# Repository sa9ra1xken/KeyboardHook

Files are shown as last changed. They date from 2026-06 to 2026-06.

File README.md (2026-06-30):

# Objective

This project aims to remodel a 1980s electronic typewriter into an online terminal in order to recreate the computing environment of the 1970s.
The project uses a Canon electronic typewriter Model S-14 which employs a daisy-wheel impact printing mechanism, manufactured in 1986.
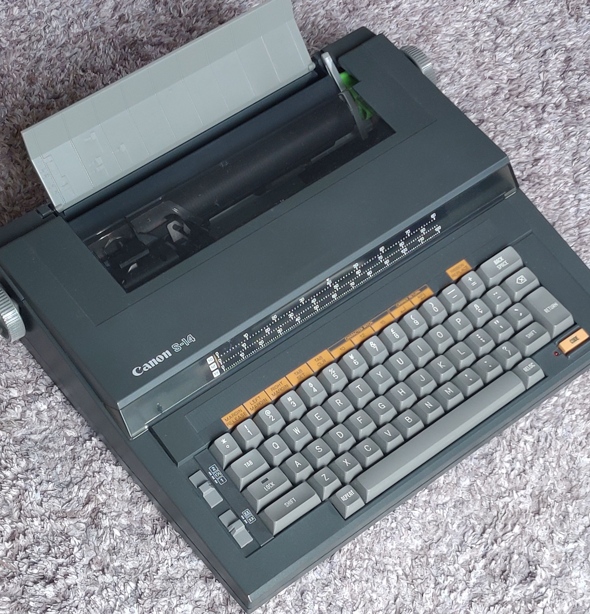
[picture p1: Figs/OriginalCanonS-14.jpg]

 
# Technical approrch

It looks the keyboard is the only available device to order printing operation, my aproach is to interfare the keyboard matrix with additionaly equipped switing device. 
An Arduino-based controller manipulates CMOS analog switches placed between scan lines and sense lines of the keyboard matrix to print characters sent from a host computer.
The controller also monitors user input by tracking behavior on the scan and sense lines, and transmits the input characters to the host.

# keyboard matrix and scan code

The keyboard matrix consists of eight scan lines and eight sense lines. Each key are maped on a pair of one scan line and one sense line. Each scan line is sequencially activated one by one. The controler knows which key is pressed by checking the sense line state at the timing each scan line is activated. 
The following table shows the key mapping in the matrix on the unit. 

|scan\sense|pin12(COL0)|pin11(COL1)|pin10(COL2)|pin9(COL3)|pin8(COL4)|pin7(COL5)|pin6(COL6)|pin5(COL7)|
|:---:|:---:|:---:|:---:|:---:|:---:|:---:|:---:|:---:|
|pin21(ROW0)|REP |A |I |Q |Y |6 |/ |TAB |
|pin20(ROW1)|SHIFT |B |J |R |Z |7 |^ |DEL |
|pin19(ROW2)|LOCK |C |K |S |0 |8 |- |REPEAT |
|pin18(ROW3)| |D |L |T |1 |9 |= |BS |
|pin17(ROW4)| |E |M |U |2 |, |β |CODE |
|pin16(ROW5)| |F |N |V |3 |. | | |
|pin15(ROW6)| |G |O |W |4 |, |° | |
|pin14(ROW7)| |H |P |X |5 |. |space | |

In the Arduino internal process, a key press is represented by the intermediate byte of information called the scan code.
Below is the bit structure of the scan code.

|Bit7|Bit6|Bit5|Bit4|Bit3|bit2|Bit1|Bit0|
|----|----|----|----|----|----|----|----|
|0 |0 |C[2]|C[1]|C[0]|R[2]|R[1]|R[0]|

C[i] means bit i in the binary encoded colmn number, R[j] means bit j in the binary encoded row number.

# Handshaking

Since the printing speed of the typewriter is usually much slower than the host computer, we have to implement some mechanism to synchronaize the data rate between them. The mechanism makes the host computer wait sending character untile the typewriter has processed the last character.
In order to know the state of mechanical behavior in the typewriter, a couple of logic signal on the embeded controller IC7 (HD6301Y) on the main typewriter control board are monitored by the adapter. I have discoverd these signals by some oscilloscoping.

|Signal|Function|Connection to Arduino|
|---|---|---|
|IC7.Pin24|Goes low while typing a character|D3|
|IC7.Pin16|Goes high while feeding paper|D7|

Regarding the handshaking between Arduino and the host, I initially intended to use the CTS signal on the serial port, but I couldn't get the host side to handle CTS-based handshaking. I decided to use ACK-based handshaking,   where Arduino sends back an ACK character (0x06) upon processing a character from the host.

# Printing usupported characters

Because the typewriter was originally not intended to be used with computers, several characters defined in the ASCII code table were missing. To cope with this limitation, I have implemented a method to express unsupported characters by overtyping multiple caracters. 
Below shows the unsupported characters and the replaced overtyping combination I used. 

|Original character|Replacement|
|---|---|
|'<' |'(' and '-'|
|'>' |')' and '-'|
|'{' |'(' and '='|
|'}' |')' and '='|
|'[' |'(' and '_'|
|']' |')' and '_'|
 
# Inputting unsupported characters 

There is a special button named CODE on the keyboard.
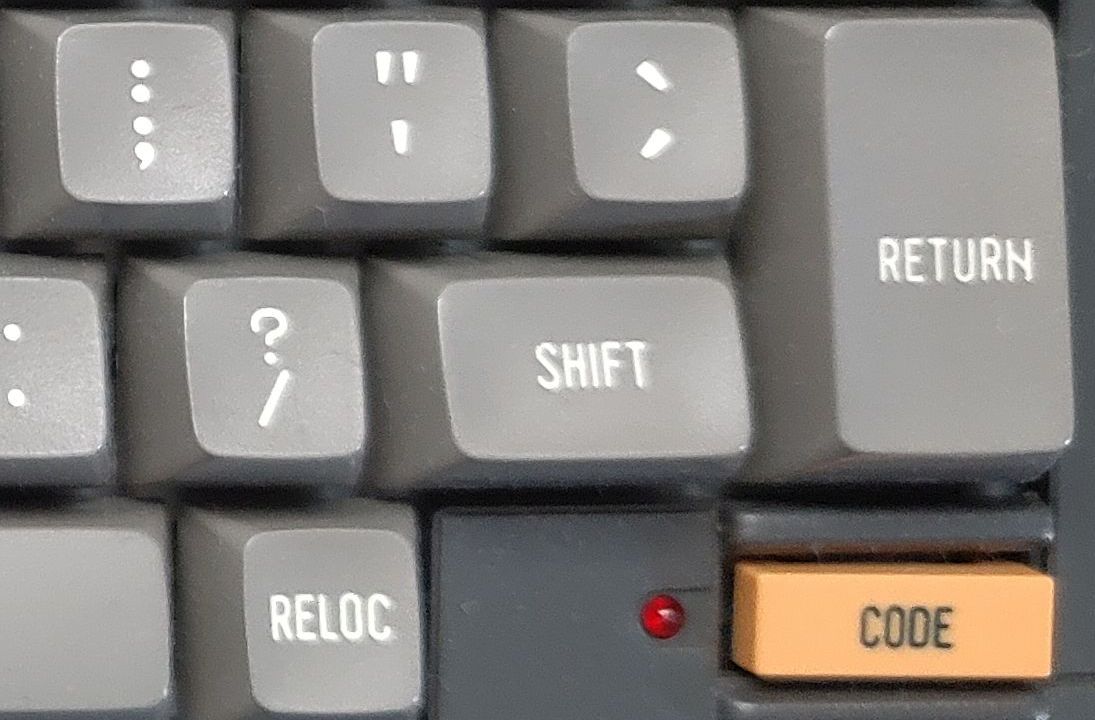
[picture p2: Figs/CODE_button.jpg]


The original function of the button is to bring the typewriter into special mode in which you can change some operating parameters such as Left and Right Margins, TAB position, character pitch, etc. I named the mode "CODE mode".         
Since pressing any of the alphabet keys when the typewriter is in CODE mode doesn't make printing action, I used CODE mode for inputting the unsupported characters and some ASCII control codes. Below shows the key functions in CODE mode I implemented.

|Key |Function in CODE mode |
|---|---|
|B |Send CTRL-B (STX) to host |
|C |Send CTRL-C (ETX) to host |
|D |Send CTRL-D (EOT) to host |
|E |Send CTRL-E (ENQ) to host |
|F |Send CTRL-F (ESC) to host |
|J |behaves as '<' key |
|K |behaves as '>' key |
|L |behaves as '[' key |
|L with SHIFT|behaves as '{' key | 
|M |behaves as ']' key |
|M with SHIFT|behaves as '}' key |  

By the way, though pressing alphabet keys in CODE mode doesn't print, some variation in behavior results, as shown in the following table. Program code in Arduino absorbs these variations.  

|Key|Behavior in CODE mode|
|--|:---|
|A|sounds beep|
|B|Print a blank character then exit CODE mode|
|C|sounds beep and exits CODE mode|
|D-I|sounds beep|
|J-M|Do nothing and exit CODE mode|
|N-Z|sounds beep|

# Sumary of adapter interface

|pin#|in/out|signal function |main board connection  |
|----|---|---|---|
|1 | | | |
|2 | | | |
|3 |in |+feed in progress  |IC7.Pin16 |
|4 | | | |
|5 | | | |
|6 | | | |
|7 |in |-print in progress |IC7.pin24 |
|8 |pass. |KBD matrix ROW0 |FFC.pin21 |
|9 |pass. |KBD matrix ROW1 |FFC.pin20 |
|10  |pass. |KBD matrix ROW2 |FFC.pin19 |
|11  |pass. |KBD matrix ROW3 |FFC.pin18 |
|12  |pass. |KBD matrix ROW4 |FFC.pin17 |
|13  |pass. |KBD matrix ROW6 |FFC.pin16 |
|14  |pass. |KBD matrix ROW6 |FFC.pin15 |
|15  |pass. |KBD matrix ROW7 |FFC.pin14 |
|16  |pass. |KBD matrix COL0 |FFC.pin13 |
|17  |pass. |KBD matrix COL1 |FFC.pin12 |
|18  |pass. |KBD matrix COL2 |FFC.pin11 |
|19  |pass. |KBD matrix COL3 |FFC.pin10 |
|20  |pass. |KBD matrix COL4 |FFC.pin9 |
|21  |pass. |KBD matrix COL5 |FFC.pin8 |
|22  |pass. |KBD matrix COL6 |FFC.pin7 |
|23  |pass. |KBD matrix COL7 |FFC.pin6 |
|24  |power |ground |FFC.pin5 |
|25  | | |FFC.pin4 |
|26  |in |-shift lock |FFC.pin3 |
|27  |in |-CODE mode |FFC.pin2 |
|28  |power |power supply(+5V)  |FFC.pin1 |

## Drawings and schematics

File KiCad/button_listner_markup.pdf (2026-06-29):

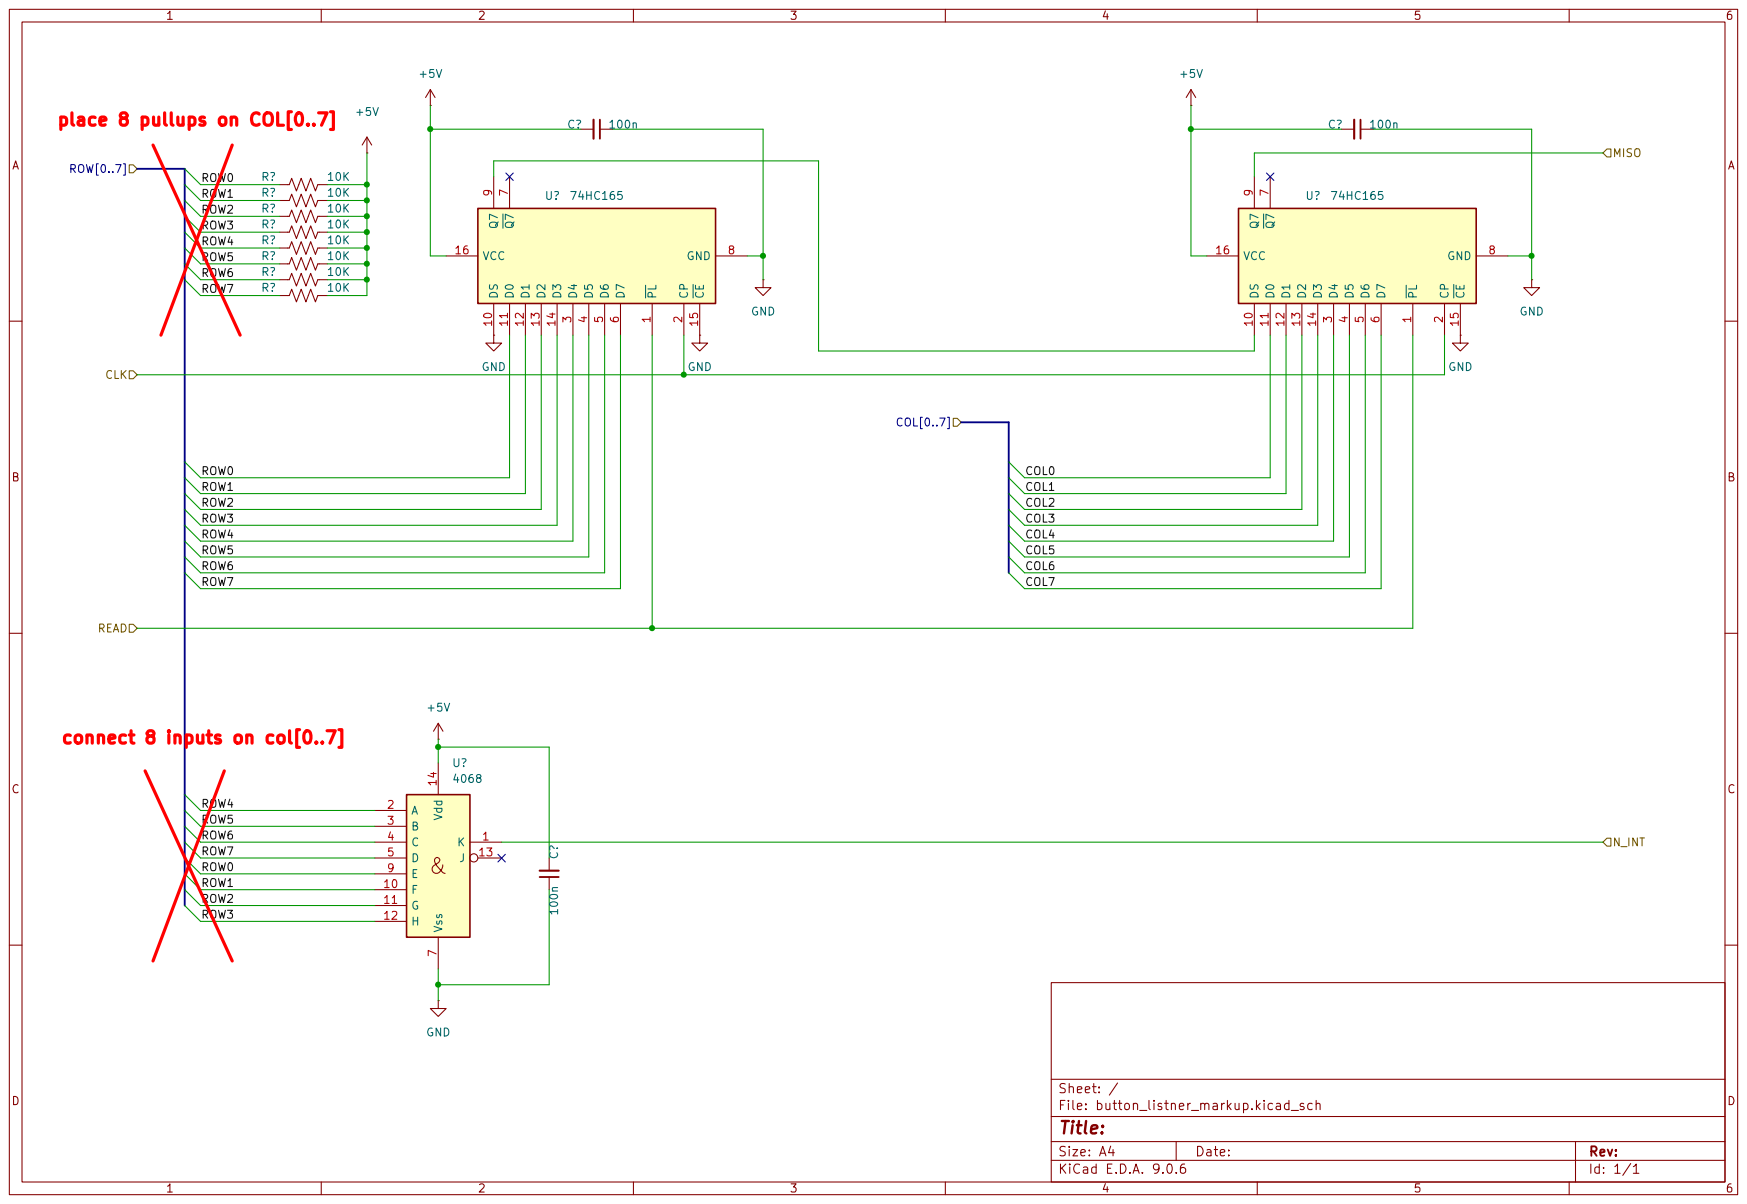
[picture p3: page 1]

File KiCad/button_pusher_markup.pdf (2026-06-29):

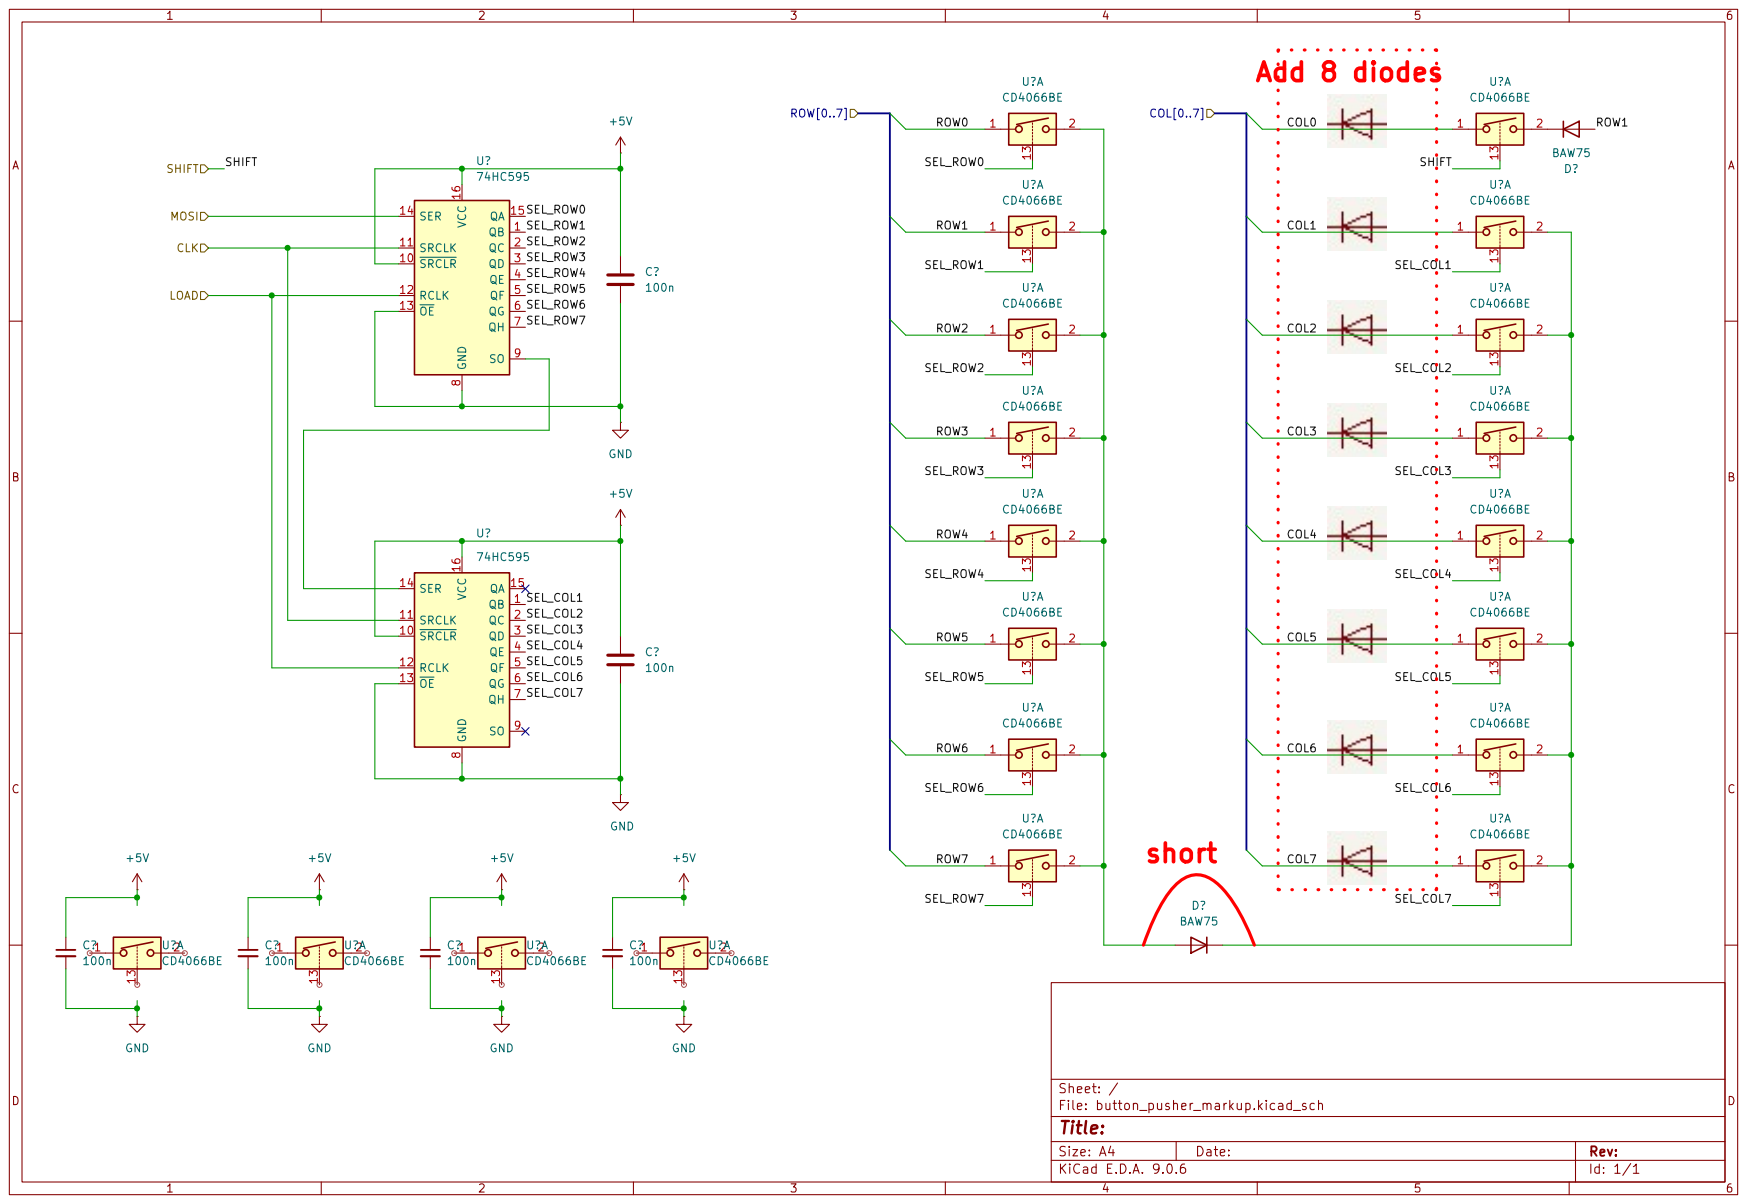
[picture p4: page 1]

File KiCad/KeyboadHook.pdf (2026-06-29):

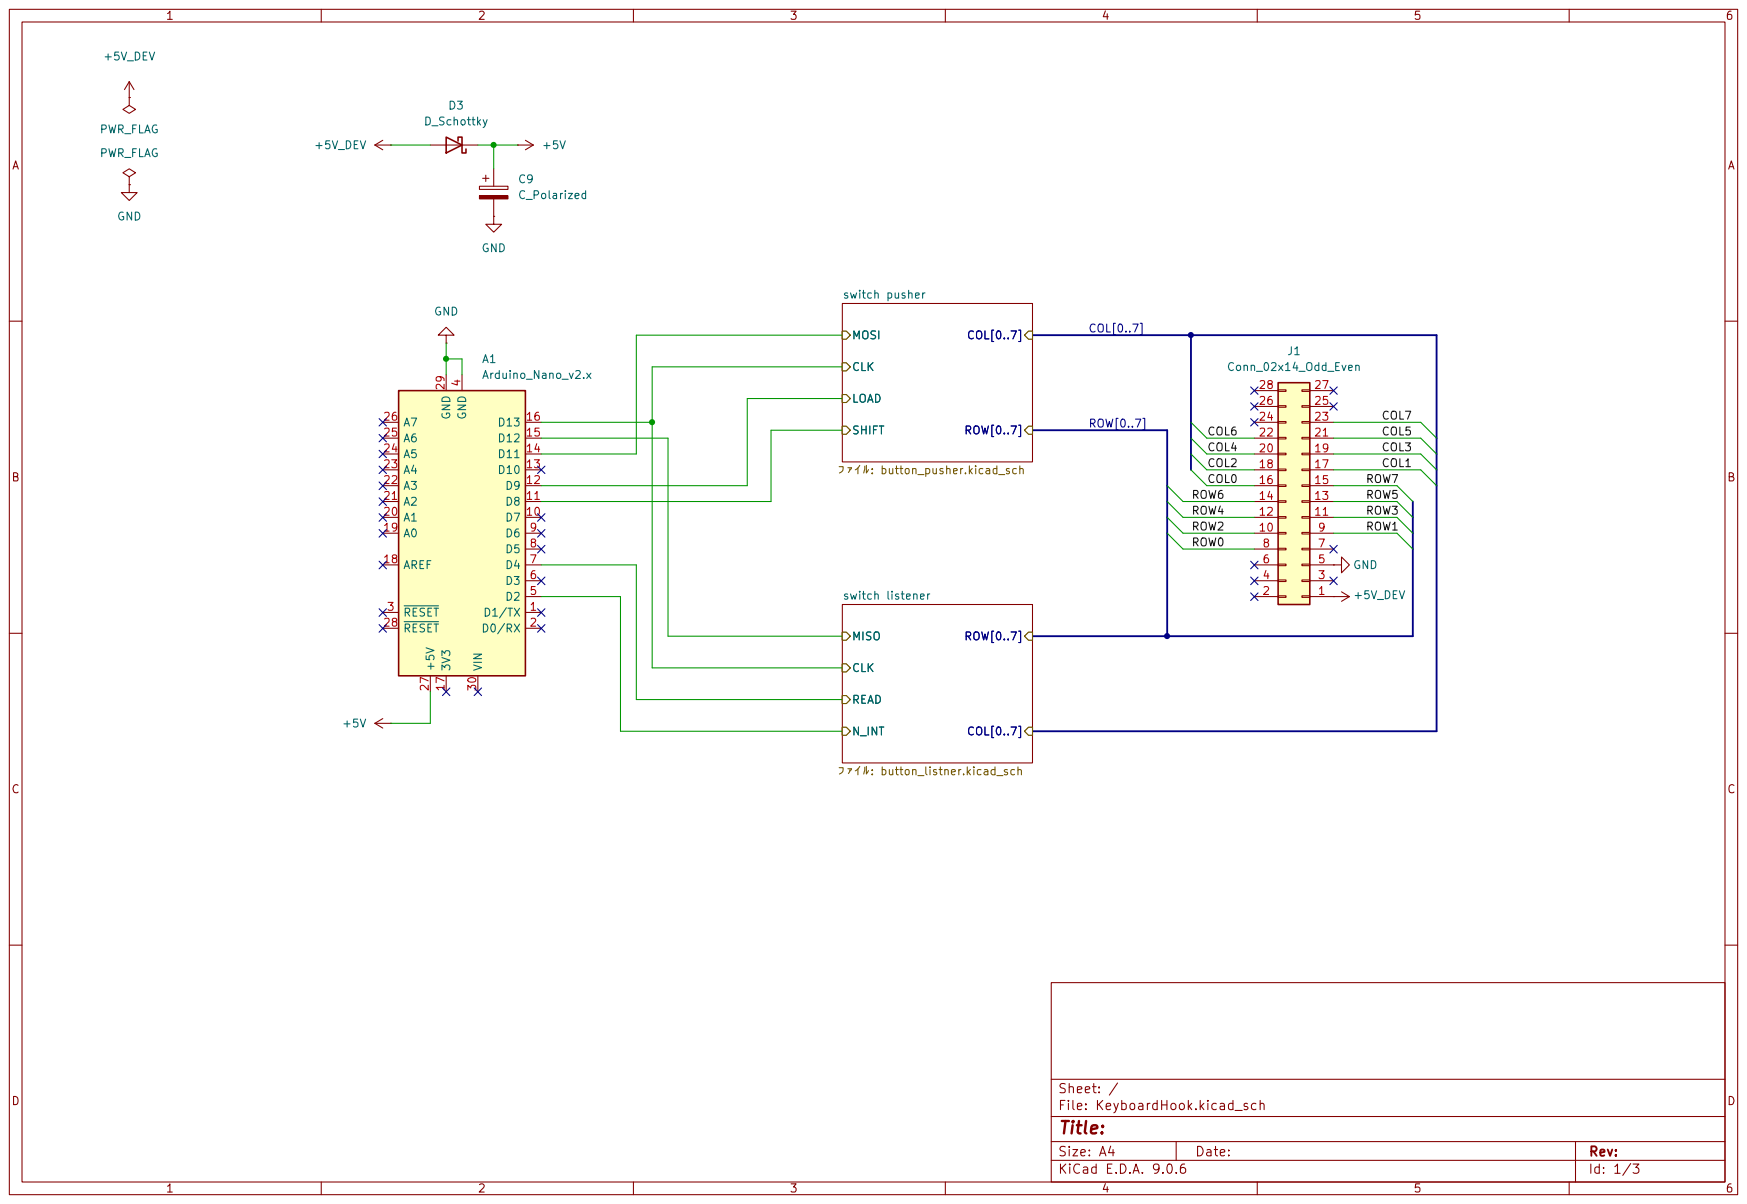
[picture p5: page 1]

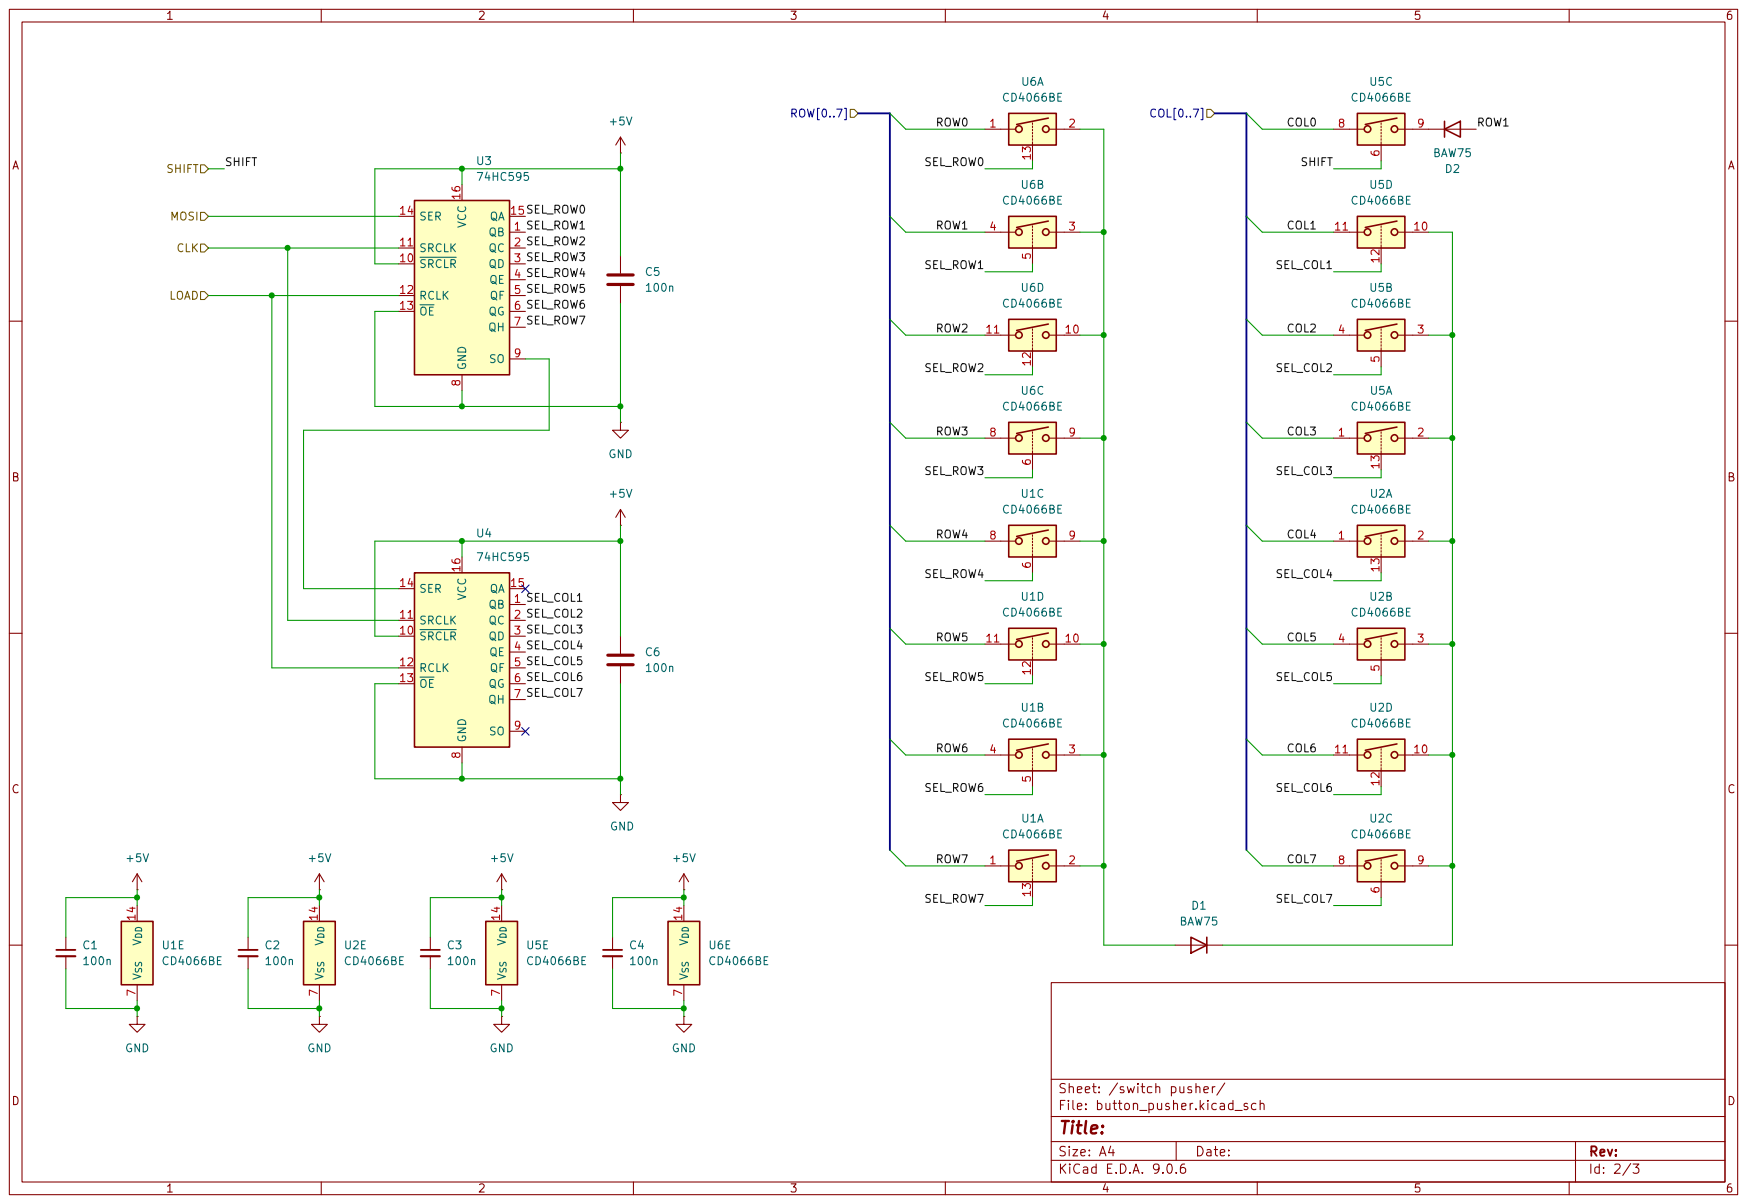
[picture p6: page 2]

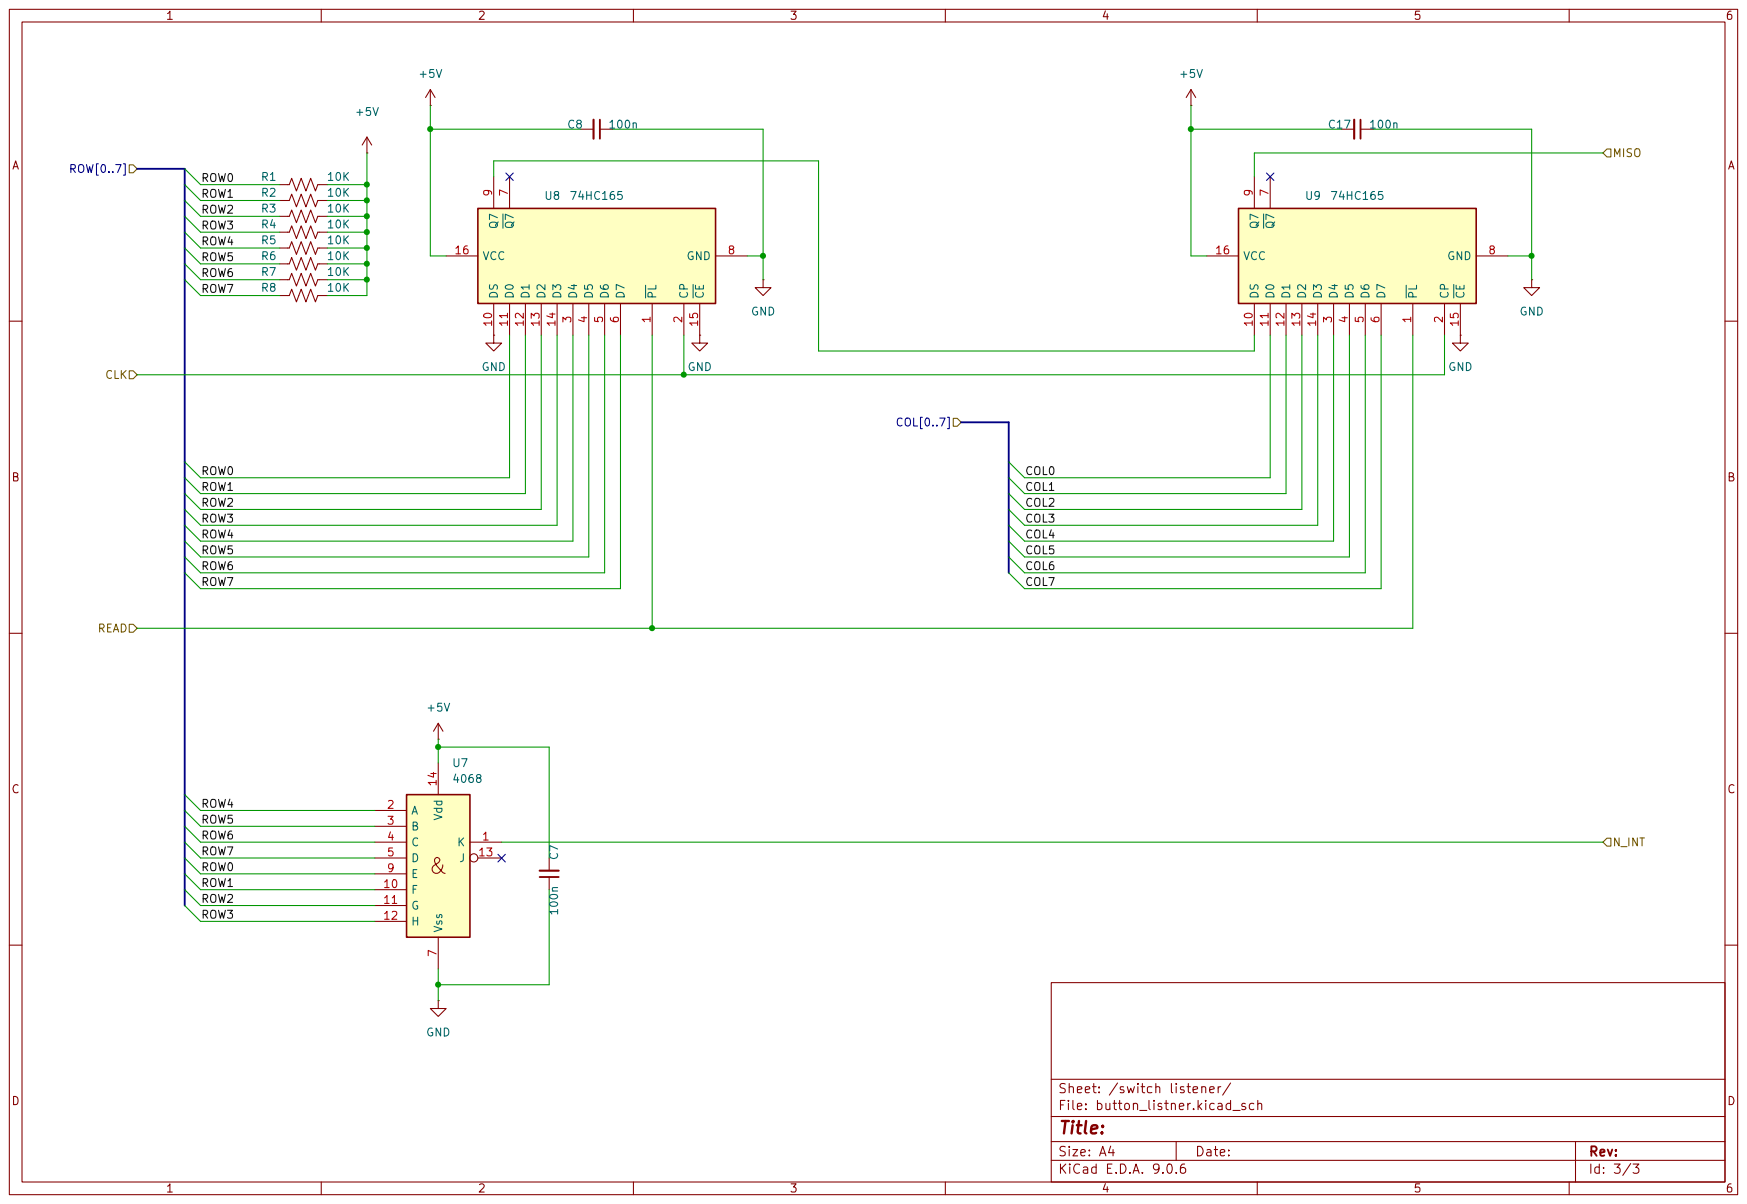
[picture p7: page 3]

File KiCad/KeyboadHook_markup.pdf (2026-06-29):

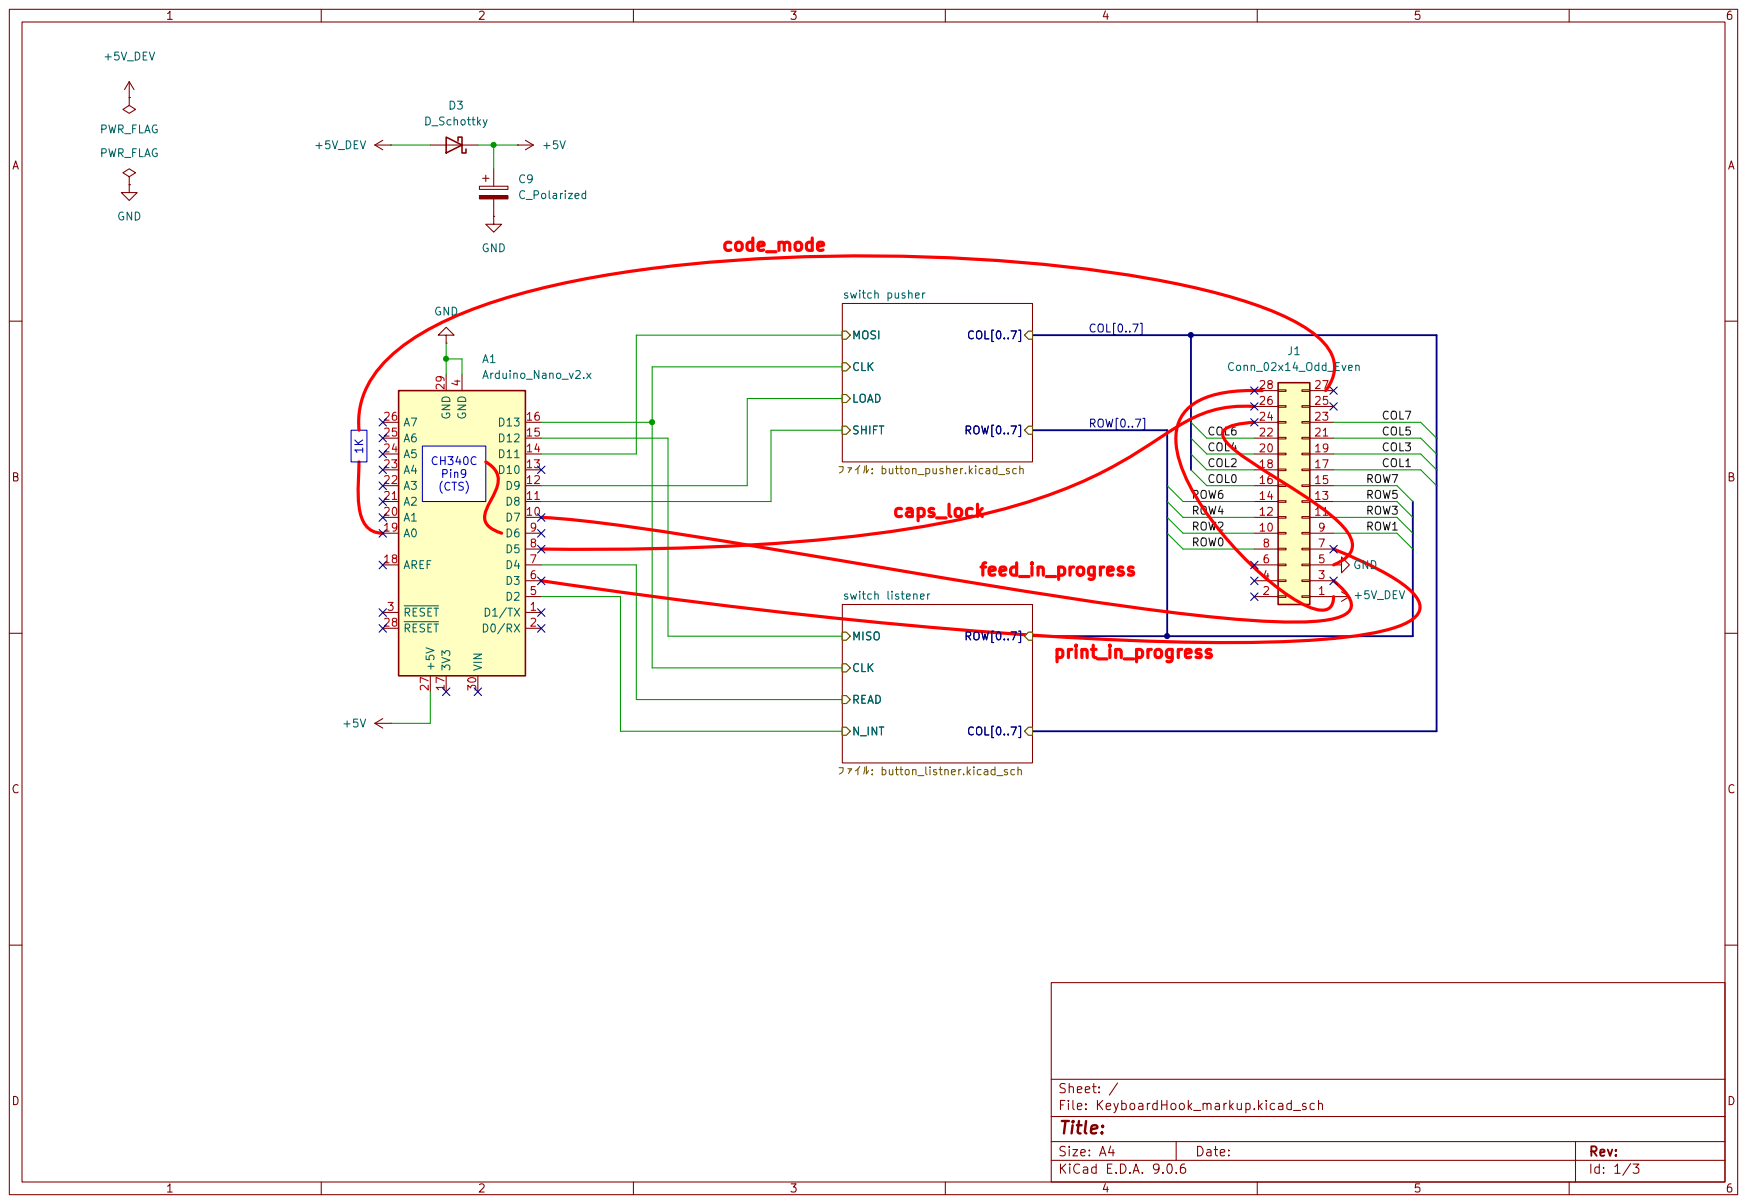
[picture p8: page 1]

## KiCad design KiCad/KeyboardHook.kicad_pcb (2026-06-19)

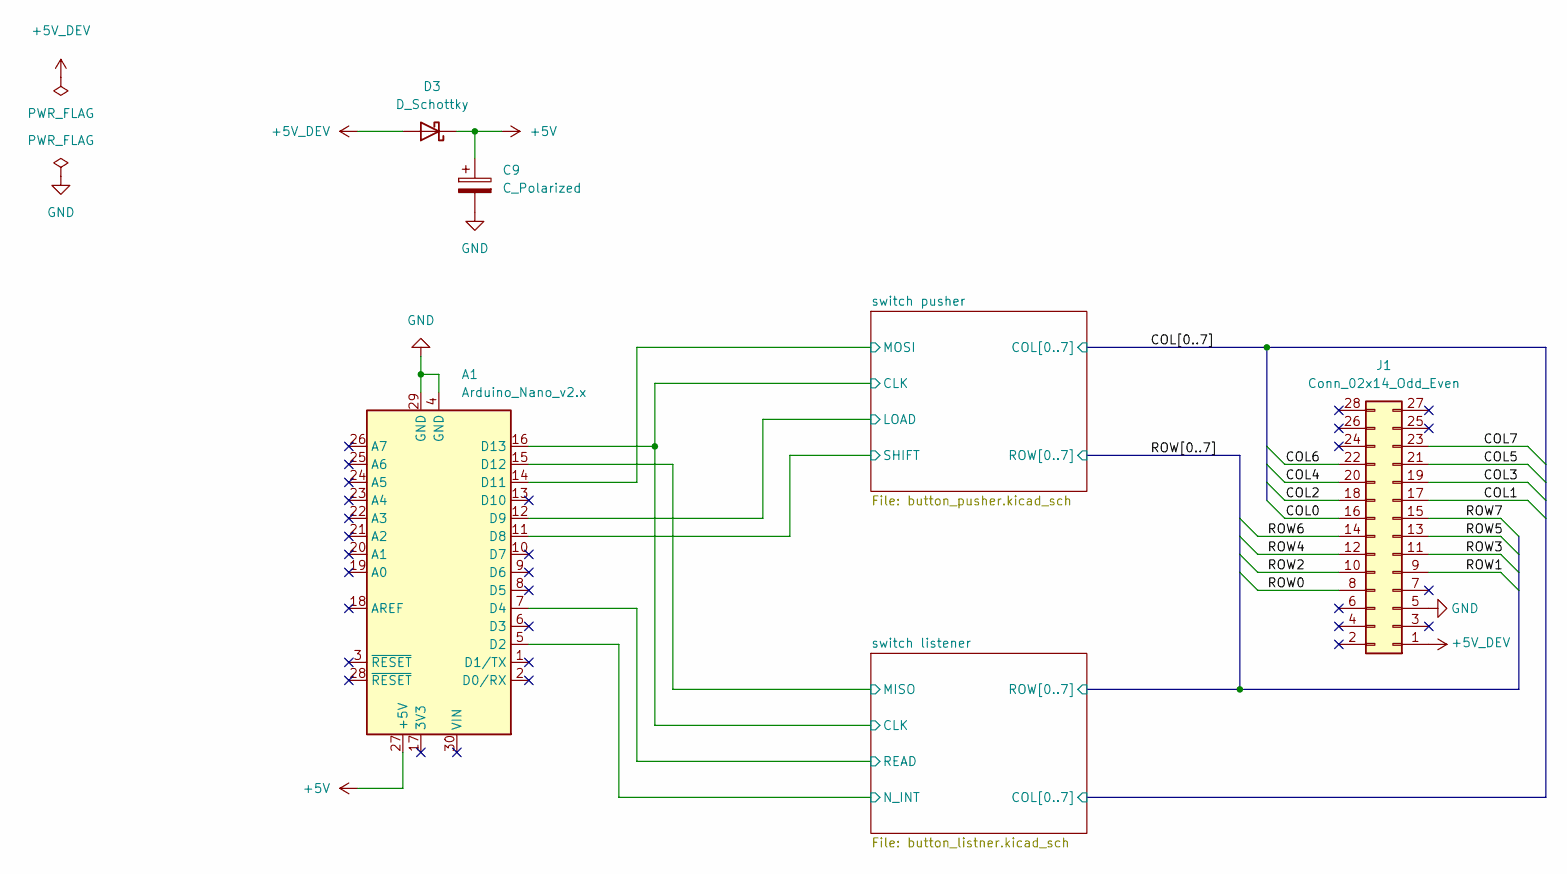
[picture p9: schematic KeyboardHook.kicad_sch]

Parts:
A1: Arduino_Nano_v2.x; Arduino_Nano
C9: C_Polarized; CP_Radial_D6.3mm_P2.50mm
D3: D_Schottky; D_DO-35_SOD27_P10.16mm_Horizontal
J1: Conn_02x14_Odd_Even; PinSocket_2x14_P2.54mm_Horizontal

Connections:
+5V: A1.27 (+5V), C9.1, D3.1 (K); also elsewhere on the board
+5V_DEV: D3.2 (A), J1.1
/COL0: J1.16; also elsewhere on the board
/COL1: J1.17; also elsewhere on the board
/COL2: J1.18; also elsewhere on the board
/COL3: J1.19; also elsewhere on the board
/COL4: J1.20; also elsewhere on the board
/COL5: J1.21; also elsewhere on the board
/COL6: J1.22; also elsewhere on the board
/COL7: J1.23; also elsewhere on the board
/ROW0: J1.8; also elsewhere on the board
/ROW1: J1.9; also elsewhere on the board
/ROW2: J1.10; also elsewhere on the board
/ROW3: J1.11; also elsewhere on the board
/ROW4: J1.12; also elsewhere on the board
/ROW5: J1.13; also elsewhere on the board
/ROW6: J1.14; also elsewhere on the board
/ROW7: J1.15; also elsewhere on the board
/switch listener/CLK: A1.16 (D13); also elsewhere on the board
/switch listener/MISO: A1.15 (D12); also elsewhere on the board
/switch listener/N_INT: A1.5 (D2); also elsewhere on the board
/switch listener/READ: A1.7 (D4); also elsewhere on the board
/switch pusher/LOAD: A1.12 (D9); also elsewhere on the board
/switch pusher/MOSI: A1.14 (D11); also elsewhere on the board
/switch pusher/SHIFT: A1.11 (D8); also elsewhere on the board
GND: A1.4 (GND), A1.29 (GND), C9.2, J1.5; also elsewhere on the board

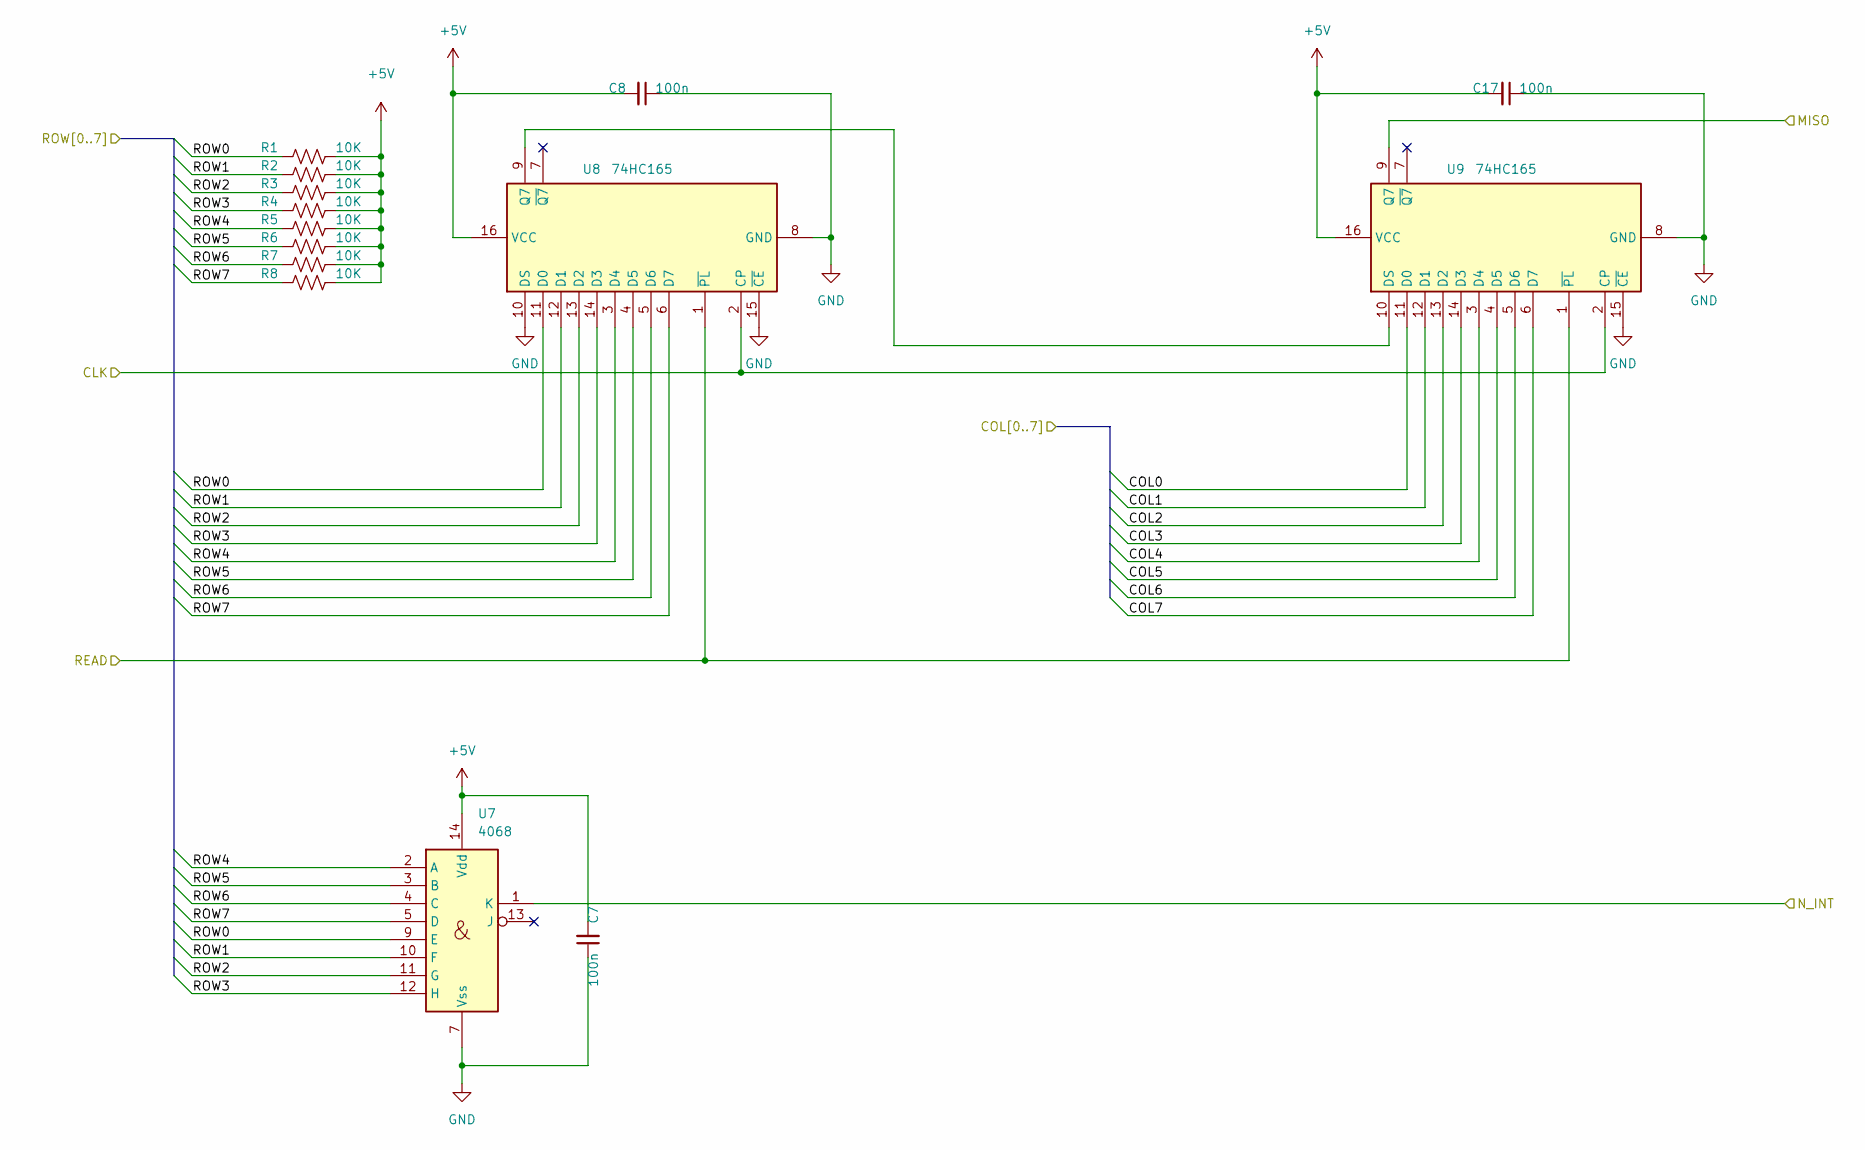
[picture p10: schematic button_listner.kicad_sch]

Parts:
C7, C8, C17: 100n; C_Disc_D4.3mm_W1.9mm_P5.00mm
R1, R2, R3, R4, R5, R6, R7, R8: 10K; R_Axial_DIN0204_L3.6mm_D1.6mm_P7.62mm_Horizontal
U7: 4068; DIP-14_W7.62mm
U8, U9: 74HC165; DIP-16_W7.62mm

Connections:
+5V: C7.2, C8.2, C17.2, R1.2, R2.2, R3.2, R4.2, R5.2, R6.2, R7.2, R8.2, U7.14 (Vdd), U8.16 (VCC), U9.16 (VCC); also elsewhere on the board
/COL0: U9.11 (D0); also elsewhere on the board
/COL1: U9.12 (D1); also elsewhere on the board
/COL2: U9.13 (D2); also elsewhere on the board
/COL3: U9.14 (D3); also elsewhere on the board
/COL4: U9.3 (D4); also elsewhere on the board
/COL5: U9.4 (D5); also elsewhere on the board
/COL6: U9.5 (D6); also elsewhere on the board
/COL7: U9.6 (D7); also elsewhere on the board
/ROW0: R1.1, U7.9 (E), U8.11 (D0); also elsewhere on the board
/ROW1: R2.1, U7.10 (F), U8.12 (D1); also elsewhere on the board
/ROW2: R3.1, U7.11 (G), U8.13 (D2); also elsewhere on the board
/ROW3: R4.1, U7.12 (H), U8.14 (D3); also elsewhere on the board
/ROW4: R5.1, U7.2 (A), U8.3 (D4); also elsewhere on the board
/ROW5: R6.1, U7.3 (B), U8.4 (D5); also elsewhere on the board
/ROW6: R7.1, U7.4 (C), U8.5 (D6); also elsewhere on the board
/ROW7: R8.1, U7.5 (D), U8.6 (D7); also elsewhere on the board
/switch listener/CLK: U8.2 (CP), U9.2 (CP); also elsewhere on the board
/switch listener/MISO: U9.9 (Q7); also elsewhere on the board
/switch listener/N_INT: U7.1 (K); also elsewhere on the board
/switch listener/READ: U8.1 (~PL), U9.1 (~PL); also elsewhere on the board
GND: C7.1, C8.1, C17.1, U7.7 (Vss), U8.8 (GND), U8.10 (DS), U8.15 (~CE), U9.8 (GND), U9.15 (~CE); also elsewhere on the board
unnamed: U8.9 (Q7), U9.10 (DS)

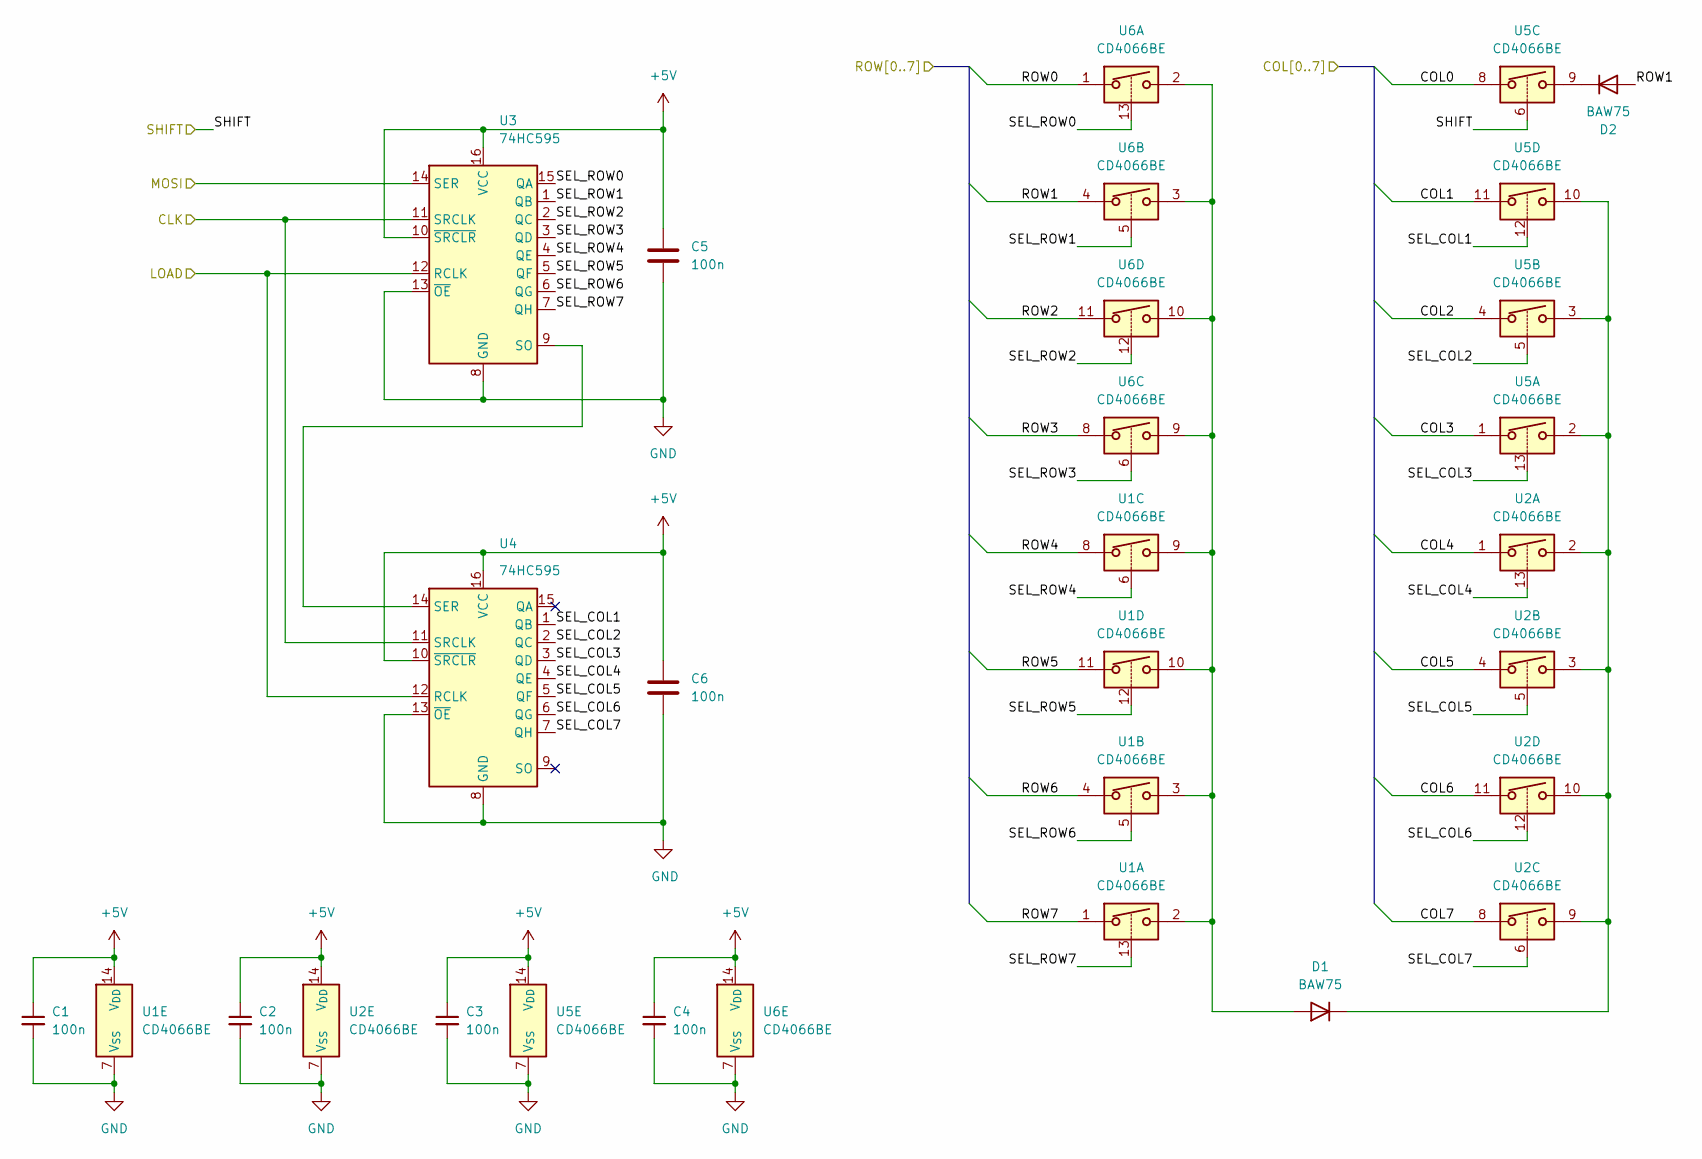
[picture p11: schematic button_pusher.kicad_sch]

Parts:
C1, C2, C3, C4, C5, C6: 100n; C_Disc_D4.3mm_W1.9mm_P5.00mm
D1, D2: BAW75; D_DO-35_SOD27_P10.16mm_Horizontal
U1, U2, U5, U6: CD4066BE; DIP-14_W7.62mm
U3, U4: 74HC595; DIP-16_W7.62mm

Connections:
+5V: C1.1, C2.1, C3.1, C4.1, C5.1, C6.1, U1.14 (V_{DD}), U2.14 (V_{DD}), U3.10 (~SRCLR), U3.16 (VCC), U4.10 (~SRCLR), U4.16 (VCC), U5.14 (V_{DD}), U6.14 (V_{DD}); also elsewhere on the board
/COL0: U5.8; also elsewhere on the board
/COL1: U5.11; also elsewhere on the board
/COL2: U5.4; also elsewhere on the board
/COL3: U5.1; also elsewhere on the board
/COL4: U2.1; also elsewhere on the board
/COL5: U2.4; also elsewhere on the board
/COL6: U2.11; also elsewhere on the board
/COL7: U2.8; also elsewhere on the board
/ROW0: U6.1; also elsewhere on the board
/ROW1: D2.2 (A), U6.4; also elsewhere on the board
/ROW2: U6.11; also elsewhere on the board
/ROW3: U6.8; also elsewhere on the board
/ROW4: U1.8; also elsewhere on the board
/ROW5: U1.11; also elsewhere on the board
/ROW6: U1.4; also elsewhere on the board
/ROW7: U1.1; also elsewhere on the board
/switch listener/CLK: U3.11 (SRCLK), U4.11 (SRCLK); also elsewhere on the board
/switch pusher/LOAD: U3.12 (RCLK), U4.12 (RCLK); also elsewhere on the board
/switch pusher/MOSI: U3.14 (SER); also elsewhere on the board
/switch pusher/SEL_COL1: U4.1 (QB), U5.12
/switch pusher/SEL_COL2: U4.2 (QC), U5.5
/switch pusher/SEL_COL3: U4.3 (QD), U5.13
/switch pusher/SEL_COL4: U2.13, U4.4 (QE)
/switch pusher/SEL_COL5: U2.5, U4.5 (QF)
/switch pusher/SEL_COL6: U2.12, U4.6 (QG)
/switch pusher/SEL_COL7: U2.6, U4.7 (QH)
/switch pusher/SEL_ROW0: U3.15 (QA), U6.13
/switch pusher/SEL_ROW1: U3.1 (QB), U6.5
/switch pusher/SEL_ROW2: U3.2 (QC), U6.12
/switch pusher/SEL_ROW3: U3.3 (QD), U6.6
/switch pusher/SEL_ROW4: U1.6, U3.4 (QE)
/switch pusher/SEL_ROW5: U1.12, U3.5 (QF)
/switch pusher/SEL_ROW6: U1.5, U3.6 (QG)
/switch pusher/SEL_ROW7: U1.13, U3.7 (QH)
/switch pusher/SHIFT: U5.6; also elsewhere on the board
GND: C1.2, C2.2, C3.2, C4.2, C5.2, C6.2, U1.7 (V_{SS}), U2.7 (V_{SS}), U3.8 (GND), U3.13 (~OE), U4.8 (GND), U4.13 (~OE), U5.7 (V_{SS}), U6.7 (V_{SS}); also elsewhere on the board
unnamed: D1.2 (A), U1.2, U1.3, U1.9, U1.10, U6.2, U6.3, U6.9, U6.10
unnamed: D1.1 (K), U2.2, U2.3, U2.9, U2.10, U5.2, U5.3, U5.10
unnamed: D2.1 (K), U5.9
unnamed: U3.9 (SO), U4.14 (SER)

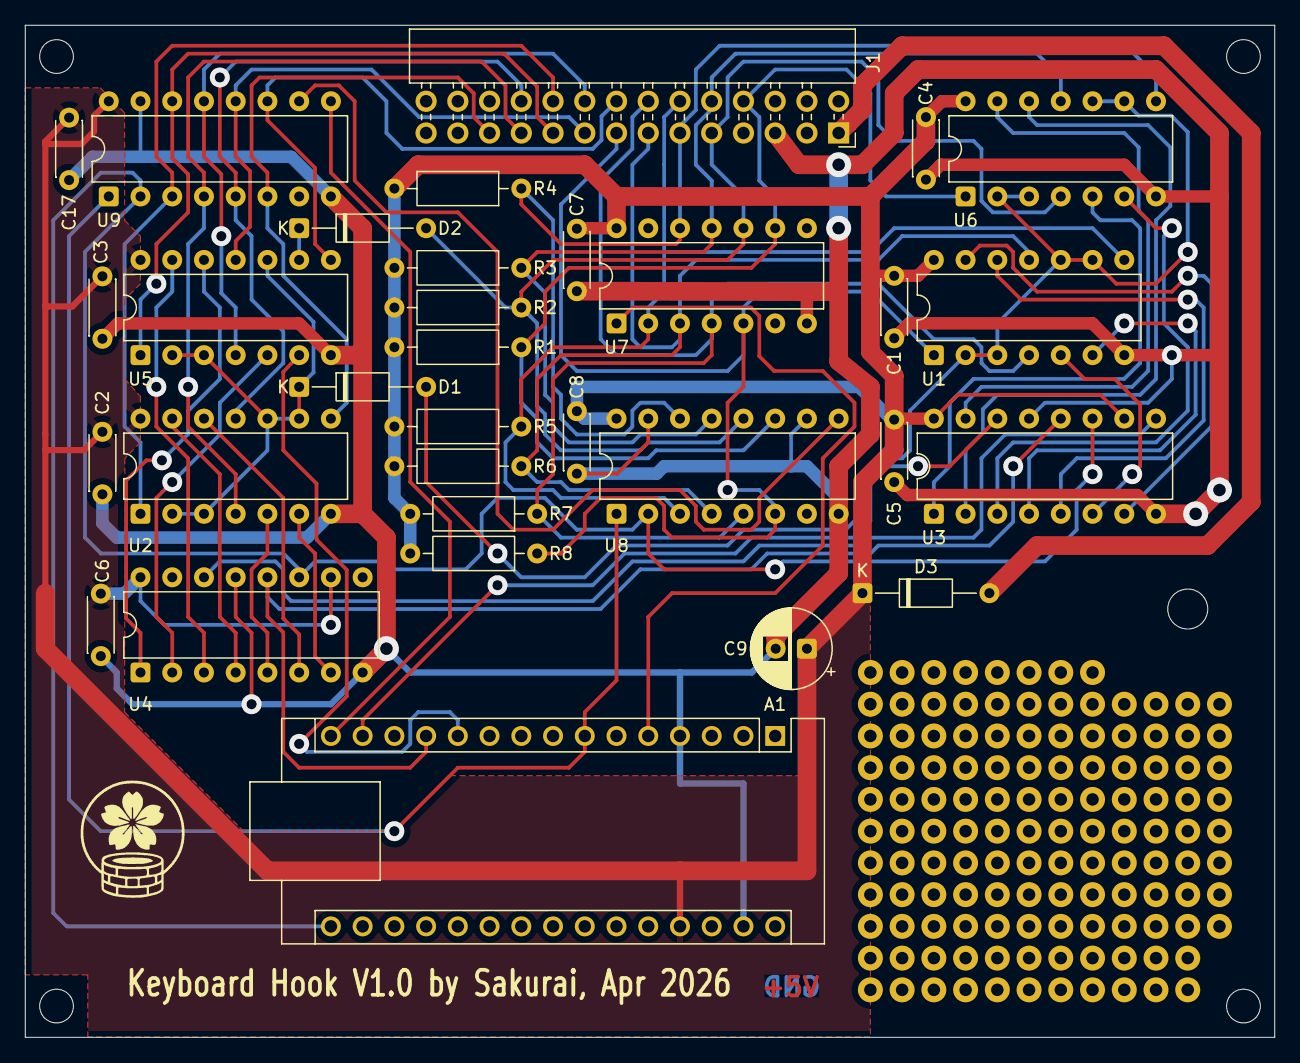
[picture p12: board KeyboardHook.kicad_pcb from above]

Board: 2 copper layers, 100.0 x 81.0 mm, 32 parts (0 on the bottom side), 46 nets.

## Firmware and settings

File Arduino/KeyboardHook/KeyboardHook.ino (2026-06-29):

#include "SpiBus.h"
#include "Listner.h"
#include "Printer.h"
#include <MsTimer2.h>
#include "AsciiCode.h"

const int scanTimingPin = 2;
const int _printingPin = 3;
const int inputLatchPin = 4;
const int _capsPin = 5;
const int _ctsPin = 6;
const int feedingPin = 7;
const int outputLatchPin = 9;  
const int _codePin = A0;

const int Waiting4SOP = A1;
const int Waiting4SOF = A2;
const int Waiting4EOA = A3;

uint8_t scan_intr;

Printer printer(scan_intr, _codePin, outputLatchPin, _printingPin, feedingPin, Waiting4SOP, Waiting4SOF, Waiting4EOA);
Listner listner(&printer, inputLatchPin, _capsPin, _codePin);

void setup() {
    pinMode(scanTimingPin, INPUT_PULLUP);
    pinMode(_ctsPin, OUTPUT);
    pinMode(outputLatchPin, OUTPUT);
    pinMode(_printingPin, INPUT_PULLUP);
    pinMode(feedingPin, INPUT_PULLUP);
    pinMode(inputLatchPin, OUTPUT);
    pinMode(_capsPin, INPUT_PULLUP);
    pinMode(_codePin, INPUT_PULLUP);
    scan_intr = digitalPinToInterrupt(scanTimingPin);     
    Serial.begin(9600);
    while (!Serial) { }
    //Serial.print("interrupt:");Serial.println(scan_intr);
    SpiBus::begin();
    listner.begin();
    printer.begin();
#ifdef USE_CTS    
    digitalWrite(_ctsPin,LOW);
#endif     
    attachInterrupt(scan_intr, onScanISR, RISING);
}

void onScanISR() {
    listner.onScan();
}

void loop() {
    if (Serial.available() > 0) {
        if ((digitalRead(_codePin)==HIGH)&&listner.isAllOff()){
            printer.type(Serial.read());
            Serial.write(ASC_ACK);    
        }
    }
    int code = listner.getAsciiCode();
    if (code>ASC_NUL){
        Serial.write(code);
    }
}

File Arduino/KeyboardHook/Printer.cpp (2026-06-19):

#include "Printer.h"
#include <avr/pgmspace.h>
#include "ScanCode.h"

uint8_t Printer::decode3to8(int value){
    uint8_t temp = 0b10000000;
    int i = 0;
    while (i < value){
        temp = temp >> 1;
        i++;
    }
    return temp;             
}

uint16_t Printer::decode(uint8_t scancode){
    uint8_t col = decode3to8((scancode>>3)&0b00000111);
    uint8_t row = decode3to8(scancode&0b00000111);
    //uint8_t shift = scancode & 0b10000000;
    uint16_t modefier = 0x0000;
    if ((scancode&SFT_UP)!=0) modefier = 0x0080;
    return (col)|(row<<8)|(modefier);
}

Printer::Printer(
    uint8_t scanInterruptNum,
    int _codePin,
    int loadPin, 
    int _pringingPin,
    int feedingPin, 
    int waitingSOP, 
    int waitingSOF, 
    int waitingEOA
    ):
    scan_intr_num(scanInterruptNum),
    _code_pin(_codePin),
    load_pin(loadPin), 
    _printing_pin(_pringingPin),
    feeding_pin(feedingPin), 
    waiting_SOP_indicator(waitingSOP),
    waiting_SOF_indicator(waitingSOF),
    waiting_EOA_indicator(waitingEOA)
    {}

void Printer::begin() {
    was_CR = false;
    SPI.begin();
    LoadSwitch(0);
    digitalWrite(waiting_SOP_indicator,LOW);
    digitalWrite(waiting_SOF_indicator,LOW);
    digitalWrite(waiting_EOA_indicator,LOW);
}

void Printer::Wait4EOP(){
    digitalWrite(waiting_EOA_indicator,HIGH);
    while(digitalRead(_printing_pin)==LOW){}
    digitalWrite(waiting_EOA_indicator,LOW);
}

void Printer::Wait4SOP(){
    digitalWrite(waiting_SOP_indicator,HIGH);
    while(digitalRead(_printing_pin)==HIGH){}
    digitalWrite(waiting_SOP_indicator,LOW);
}

void Printer::Wait4SOF(){
    digitalWrite(waiting_SOF_indicator,HIGH);
    while(digitalRead(feeding_pin)==LOW){}
    digitalWrite(waiting_SOF_indicator,LOW);
}

void Printer::Wait4EOF(){
    digitalWrite(waiting_SOF_indicator,HIGH);
    while(digitalRead(feeding_pin)==HIGH){}
    digitalWrite(waiting_SOF_indicator,LOW);
}

void Printer::Print(uint8_t scancode) {
    EIMSK &= ~(1 << scan_intr_num);
    Wait4EOP();
    LoadSwitch(decode(scancode));
    Wait4SOP();
    LoadSwitch(0);
    EIFR |= (1 << scan_intr_num);   // clear pending
    EIMSK |= (1 << scan_intr_num);
}

void Printer::PrintCRLF() {
    EIMSK &= ~(1 << scan_intr_num);
    Wait4EOF();
    LoadSwitch(decode(KEY_RETURN));
    Wait4SOF();
    LoadSwitch(0);
    Wait4EOF();
    EIFR |= (1 << scan_intr_num);   // clear pending
    EIMSK |= (1 << scan_intr_num);
}

void Printer::PrintAccent(uint8_t scancode) {
    EIMSK &= ~(1 << scan_intr_num);
    Wait4EOF();
    LoadSwitch(decode(scancode));
    Wait4SOF();
    LoadSwitch(0);
    EIFR |= (1 << scan_intr_num);   // clear pending
    EIMSK |= (1 << scan_intr_num);
}

void Printer::ResetCodeMode() {
    if (digitalRead(_code_pin) == HIGH) return;
    EIMSK &= ~(1 << scan_intr_num);
    LoadSwitch(decode(KEY_CODE));
    while (digitalRead(_code_pin)==LOW){}
    LoadSwitch(0);
    EIFR |= (1 << scan_intr_num);   // clear pending
    EIMSK |= (1 << scan_intr_num);
}

void Printer::LoadSwitch(uint16_t data) {
    SPI.beginTransaction(SPISettings(1000000, LSBFIRST, SPI_MODE0));
    digitalWrite(load_pin, LOW);
    SPI.transfer16(data);
    digitalWrite(load_pin, HIGH);
    SPI.endTransaction();
}

void Printer::type(uint8_t ascii)
{
    if (ascii == '\n'){
        if (was_CR){
            was_CR = false;
            return;
        }
        else{
            PrintCRLF();
            return;   
        }
    }

    if (ascii == '\r'){
        PrintCRLF();
        was_CR = true;
        return;
    }

    was_CR = false;

    if (ascii == '<'){
        Print(NUM_9|SFT_UP); //(
        Print(KEY_BS);          //BS
        Print(KEY_MINUS);       //-
        return;
    }

    if (ascii == '>'){
        Print(NUM_0|SFT_UP); //)
        Print(KEY_BS);          //BS
        Print(KEY_MINUS);       //-
        return;
    }

    if (ascii == '{'){
        Print(NUM_9|SFT_UP); //(
        Print(KEY_BS);          //BS
        Print(KEY_EQUAL);       //=
        return;
    }

    if (ascii == '}'){
        Print(NUM_0|SFT_UP); //)
        Print(KEY_BS);          //BS
        Print(KEY_EQUAL);       //=
        return;
    }

    if (ascii == '['){
        Print(NUM_9|SFT_UP); //(
        Print(KEY_BS);          //BS
        Print(KEY_MINUS|SFT_UP); //_
        return;
    }
    if (ascii == ']'){
        Print(NUM_0|SFT_UP); //)
        Print(KEY_BS);          //BS
        Print(KEY_MINUS|SFT_UP); //_
        return;
    }

    if (ascii == '|'){
        Print(NUM_9|SFT_UP); //(
        Print(KEY_BS);          //BS
        Print(NUM_0|SFT_UP); //)
        return;
    }

    if (ascii == '^'){
        PrintAccent(KEY_CIRCUMFLEX); //^(circumflex accent)  
        Print(KEY_SPACE); //SPC
        return;
    }

    if (ascii == '`'){
        PrintAccent(KEY_GRAVE); //^(circumflex accent)  
        Print(KEY_SPACE); //SPC
        return;
    }

    uint8_t scanCode = pgm_read_word(&ascii_to_scancode_map[ascii]);
    if (scanCode!=KEY_NOP) Print(scanCode);
    return; 
}
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
